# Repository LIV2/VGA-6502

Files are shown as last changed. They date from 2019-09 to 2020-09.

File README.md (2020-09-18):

# VGA-6502
#### 16 colours, 640x480 or 640x400
## Description
A VGA card for my homebrew computer using the Altera EPM7128 CPLD  

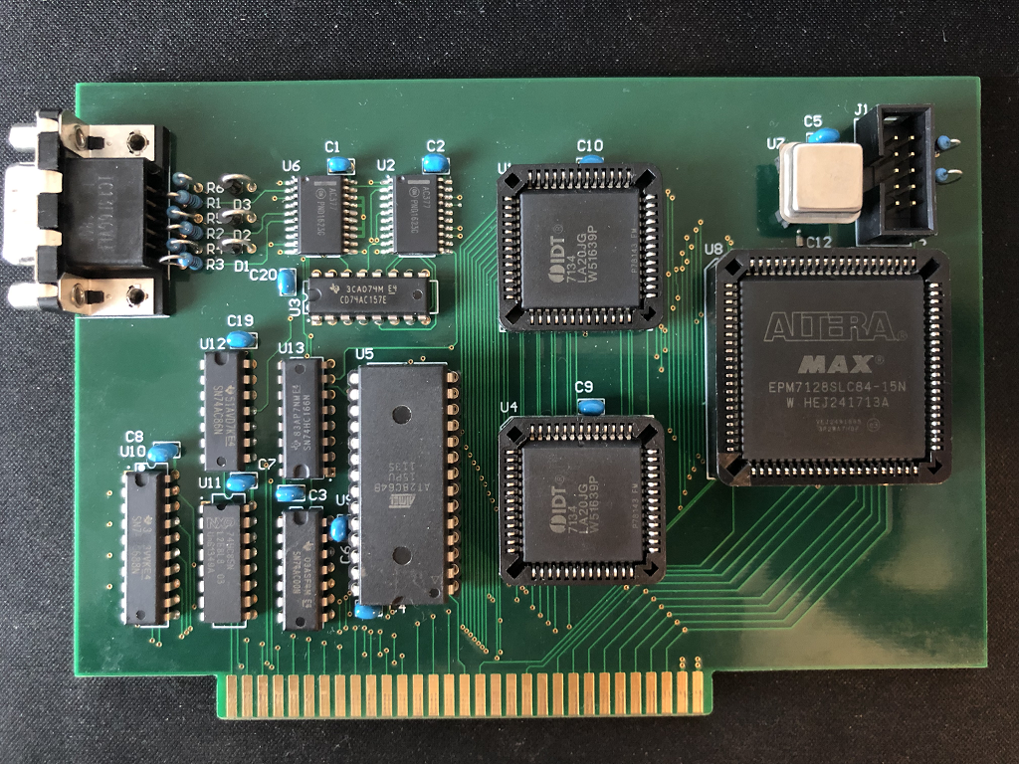
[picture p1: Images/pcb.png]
PCB
  
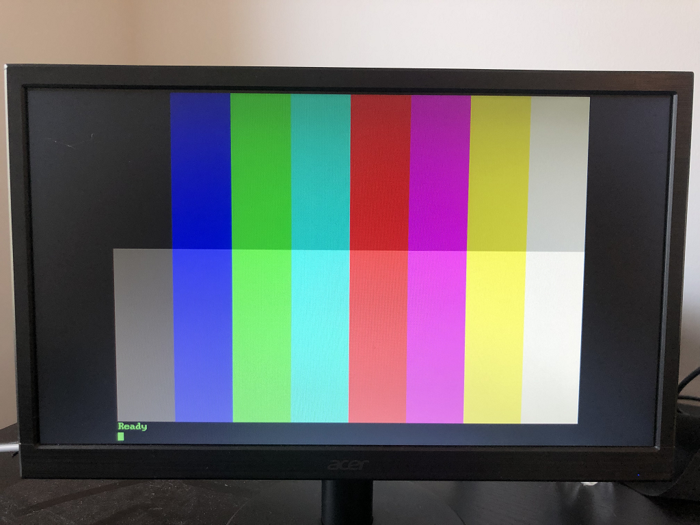
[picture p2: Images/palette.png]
Palette
  
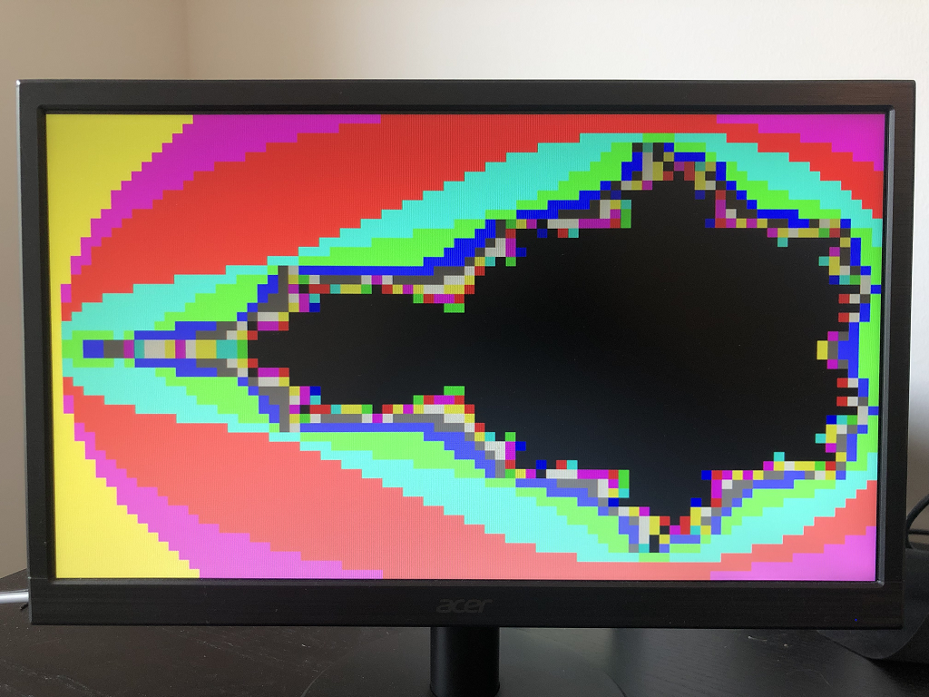
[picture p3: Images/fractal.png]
Fractal
  

Features:
* 16 Colors
* 640x480 and 640x400 modes
* Dual-port RAM
## Palette
|Low intensity|High Intensity|
|---|---|
| 0 - Black| 8 - Dark Gray|
| 1 - Red| 9 - Light Red|
| 2 - Green| 10 - Light Green|
| 3 - Yellow| 11 - Light Yellow|
| 4 - Blue| 12 - Light Blue|
| 5 - Magenta| 13- Light Magenta|
| 6 - Cyan| 14 - Light Cyan|
| 7 - Light Gray| 15 - White|

## Memory layout

### Memory map
GPU: $DF00 (configurable with J5-8)  
RAM: $A000-$BFFF (configurable with J2-4)

### Video RAM
Characters are stored on even addresses, followed by their colour on odd addresses.  
Foreground colour is stored in the lower nibble of the colour byte(s) while background colour is stored in the higher nibble of the colour byte(s)

Example: "Hello world!" with a green foreground and black background would be stored in memory as follows:

|$00|$01|$02|$03|$04|$05|$06|$07|$08|$09|$0A|$0B|$0C|$0D|$0E|$0F|$10|$11|$12|$13|$14|$15|$16|$17|
|---|---|---|---|---|---|---|---|---|---|---|---|---|---|---|---|---|---|---|---|---|---|---|---|
'H'|$0A|'e'|$0A|'l'|$0A|'l'|$0A|'o'|$0A|' '|$0A|'w'|$0A|'o'|$0A|'r'|$0A|'l'|$0A|'d'|$0A|'!'|$0A|

## Registers  
**All registers are currently write-only as I did not have enough space in the CPLD to allow reading from the registers.**  
$DF00: Register Pointer  
$DF01: Register set by Register pointer  

|Register|Description|
|---|---|
|$00|Memory start address(Low byte)|
|$01|Memory start address(High byte)|
|$02|Control register|
|$03|Cursor location (Low byte)|
|$04|Cursor location (High byte)|

### Register pointer (write only)
To access a register you first need to write the register address to the register pointer (default: $DF00), then read/write the register at (default: $DF01)

### Memory Start address (write only)
This register pair forms a 16-bit memory address defining the start of the visual screen, i.e at the start of each frame the VGA controller begins reading characters from here
### Control Register (write only)
The control register configures various settings for the VGA controller 

|Bit(s)|Description|
|---|---|
|7|Character ROM bank select|
|6|Cursor Enable|
|5|Cursor Flash|
|4|Mode|
|3..0|Character Height|

**Bank Select:** Switch font (only valid in Mode 1, 8 Pixel character height)  
**Cursor enable**: Enable the cursor  
**Cursor Flash**: Enable cursor flashing  
**Mode**: Mode 0: 640x480, Mode 1: 640x400  (mode 1 will select the 8x8 fonts from the CGROM)  
**Character Height**: Character height, Default: 0xF (16 pixels)

### Cursor location (write only)
This register pair forms a 16-bit address defining where the cursor should be displayed

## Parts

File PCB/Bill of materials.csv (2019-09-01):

Comment | Description | Designator | Quantity
0.1uF | Multilayer Ceramic Capacitor, Gold Max, C320 Series, 0.1 - F, - 10%, X7R, 50 V, Radial Leaded | C1, C2, C3, C4, C5, C6, C7, C8, C9, C10, C19, C20 | 12
0.1uF | 0603 0.1uF Capacitor | C11, C12, C13, C14, C15, C16, C17, C18 | 8
FCI ICD15S13E6GV00LF | Conn High Density D-Sub SKT 15 POS 2.28mm Solder RA Thru-Hole 15 Terminal 1 Port | CON1 | 1
1N5818 | DO-41 diode vertically mounted | D1, D2, D3 | 3
750 | Generic through-hole resistor vertically mounted | R1, R2, R3 | 3
1k5 | 1k5, Generic through-hole resistor vertically mounted, Generic through-hole resistor vertically mounted | R4, R5, R6 | 3
1k | 1k | R7 | 1
10k | Generic through-hole resistor vertically mounted | R8 | 1
IDT7134LA20JG | 4K x 8 DUAL-PORT STATIC SRAM | U1, U4 | 2
74AC377 | Flip Flop D-Type Bus Interface Pos-Edge 1-Element Automotive 20-Pin SOIC W Tube | U2, U6 | 2
74HC157N | Logic IC - Multiplexer Texas Instruments SN74HC157N Multiplexer Single supply PDIP 16 | U3 | 1
AT28C64B | AT28C64B Series 64 KB (8 K x 8) 5.5 V High-Performance Parallel EEPROM - DIP-28 | U5 | 1
OSC | Oscillator XO 5MHz ??50ppm 50pF (Stability) HCMOS/TTL 55% 5V 4-Pin Metal DIP Thru-Hole Tray | U7 | 1
EPM7128SLC84-15N | CPLD MAX 7000 Family 2.5K Gates 128 Macro Cells 76.9MHz 5V 84-Pin PLCC | U8 | 1
74AC00N | Semiconductors and Actives, Logic Gates, Single, Logic, Standard | U9 | 1
74HC688N | 8-Bit Identity/Magnitude Comparators (P=Q) with Enable 20-PDIP -40 to 85 | U10 | 1
74HC85N | Magnitude Comparator 4-Bit Non-Inverting 16-Pin PDIP Tube | U11 | 1
74AC86E | XOR Gate 4-Element 2-IN CMOS 14-Pin PDIP Tube | U12 | 1
74AC166 | Shift Register Single 8-Bit Serial/Parallel to Serial 16-Pin PDIP Bulk | U13 | 1

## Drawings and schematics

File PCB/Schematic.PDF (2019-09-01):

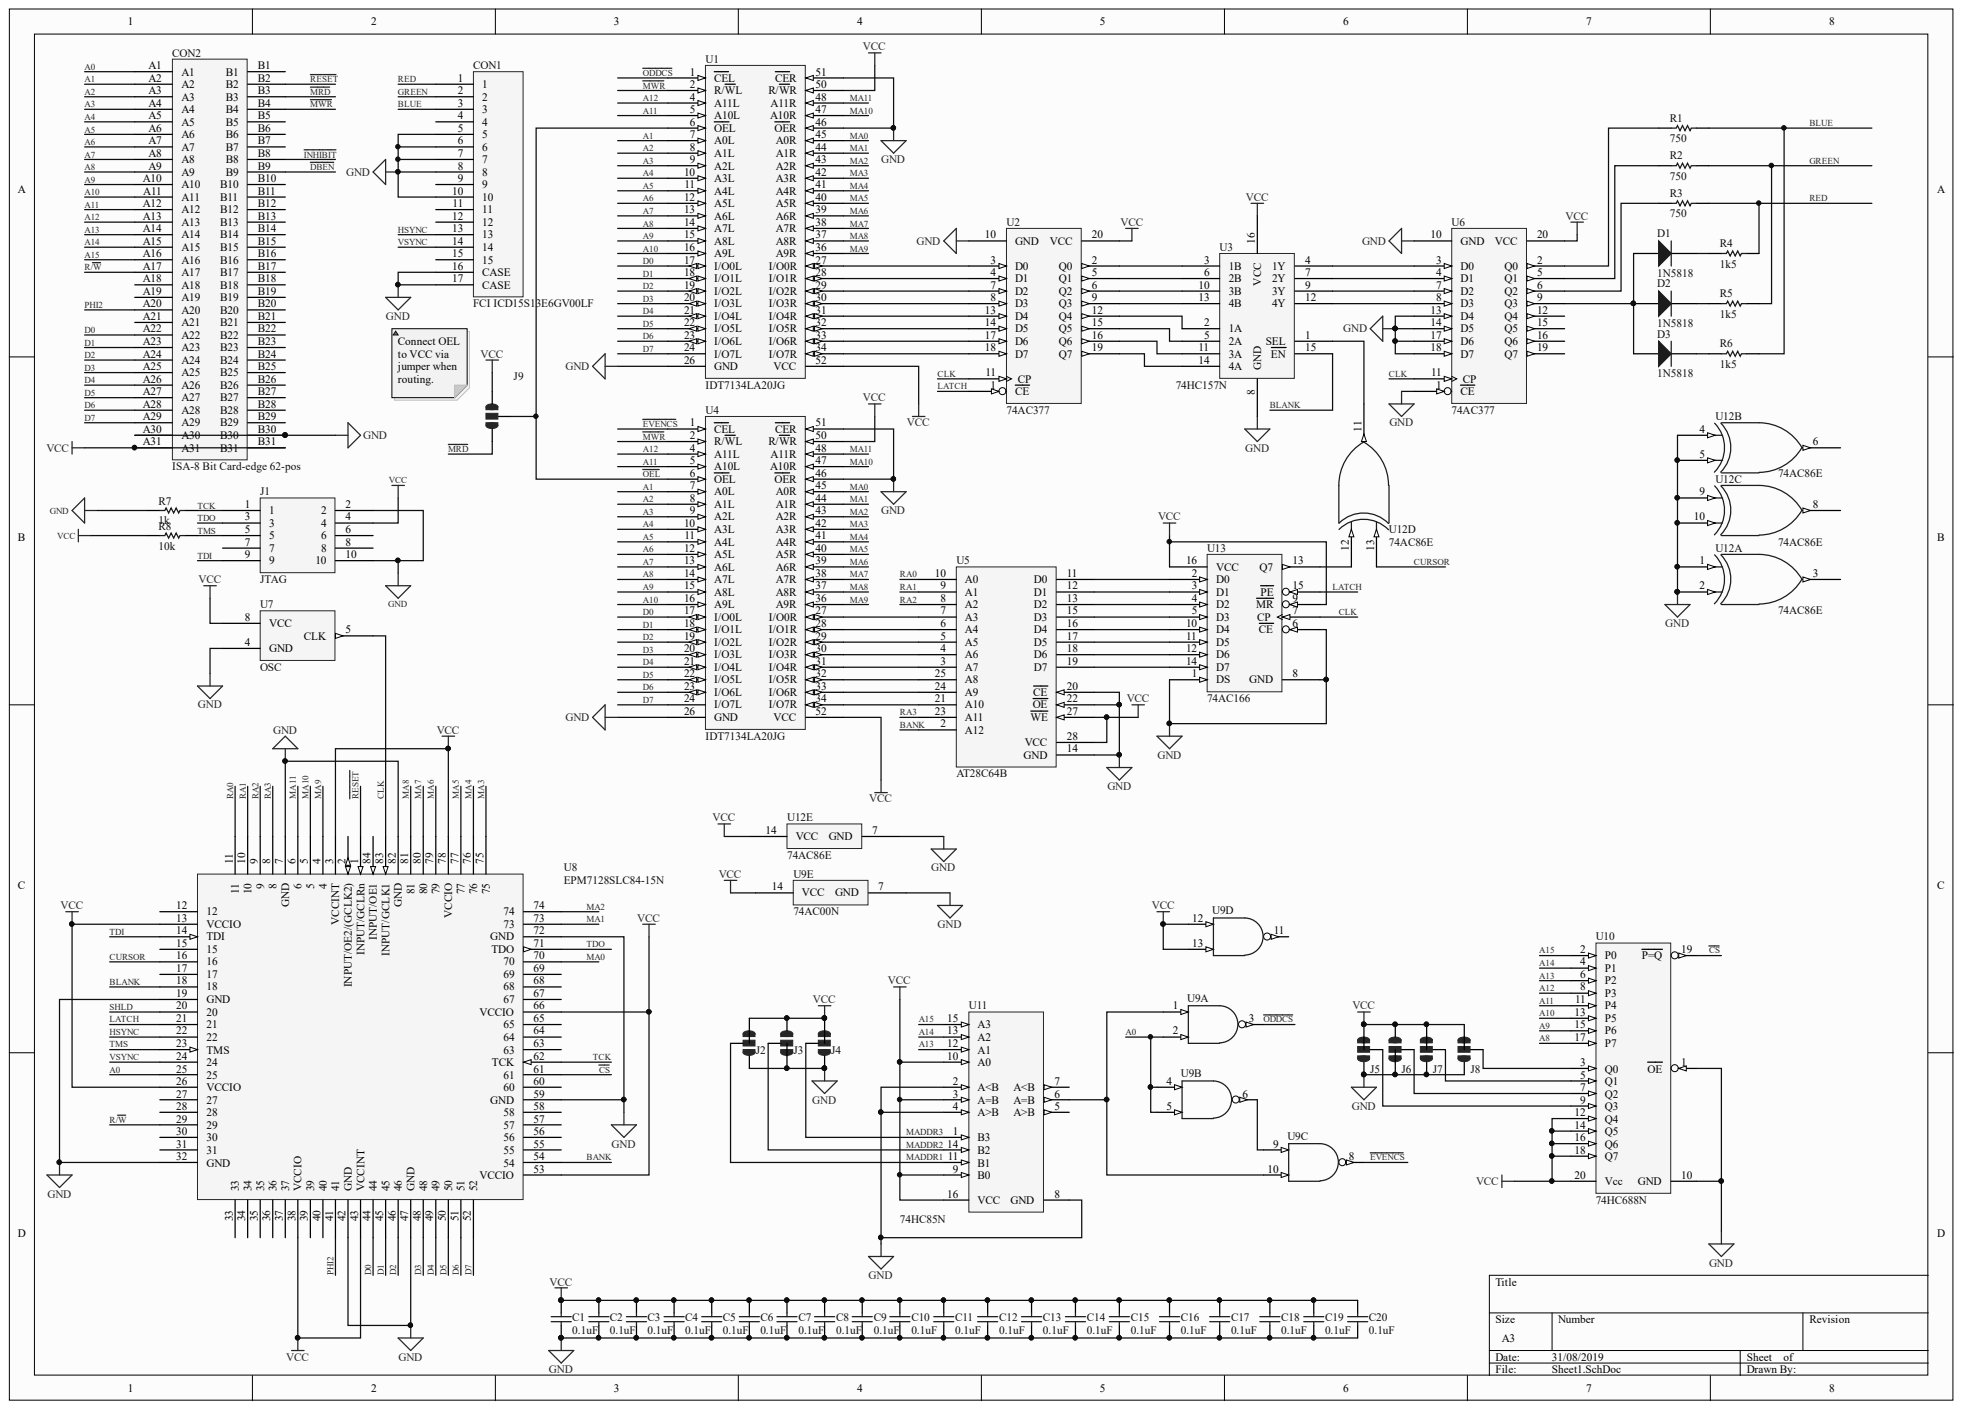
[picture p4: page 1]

ISA-8 Bit Card-edge 62-pos

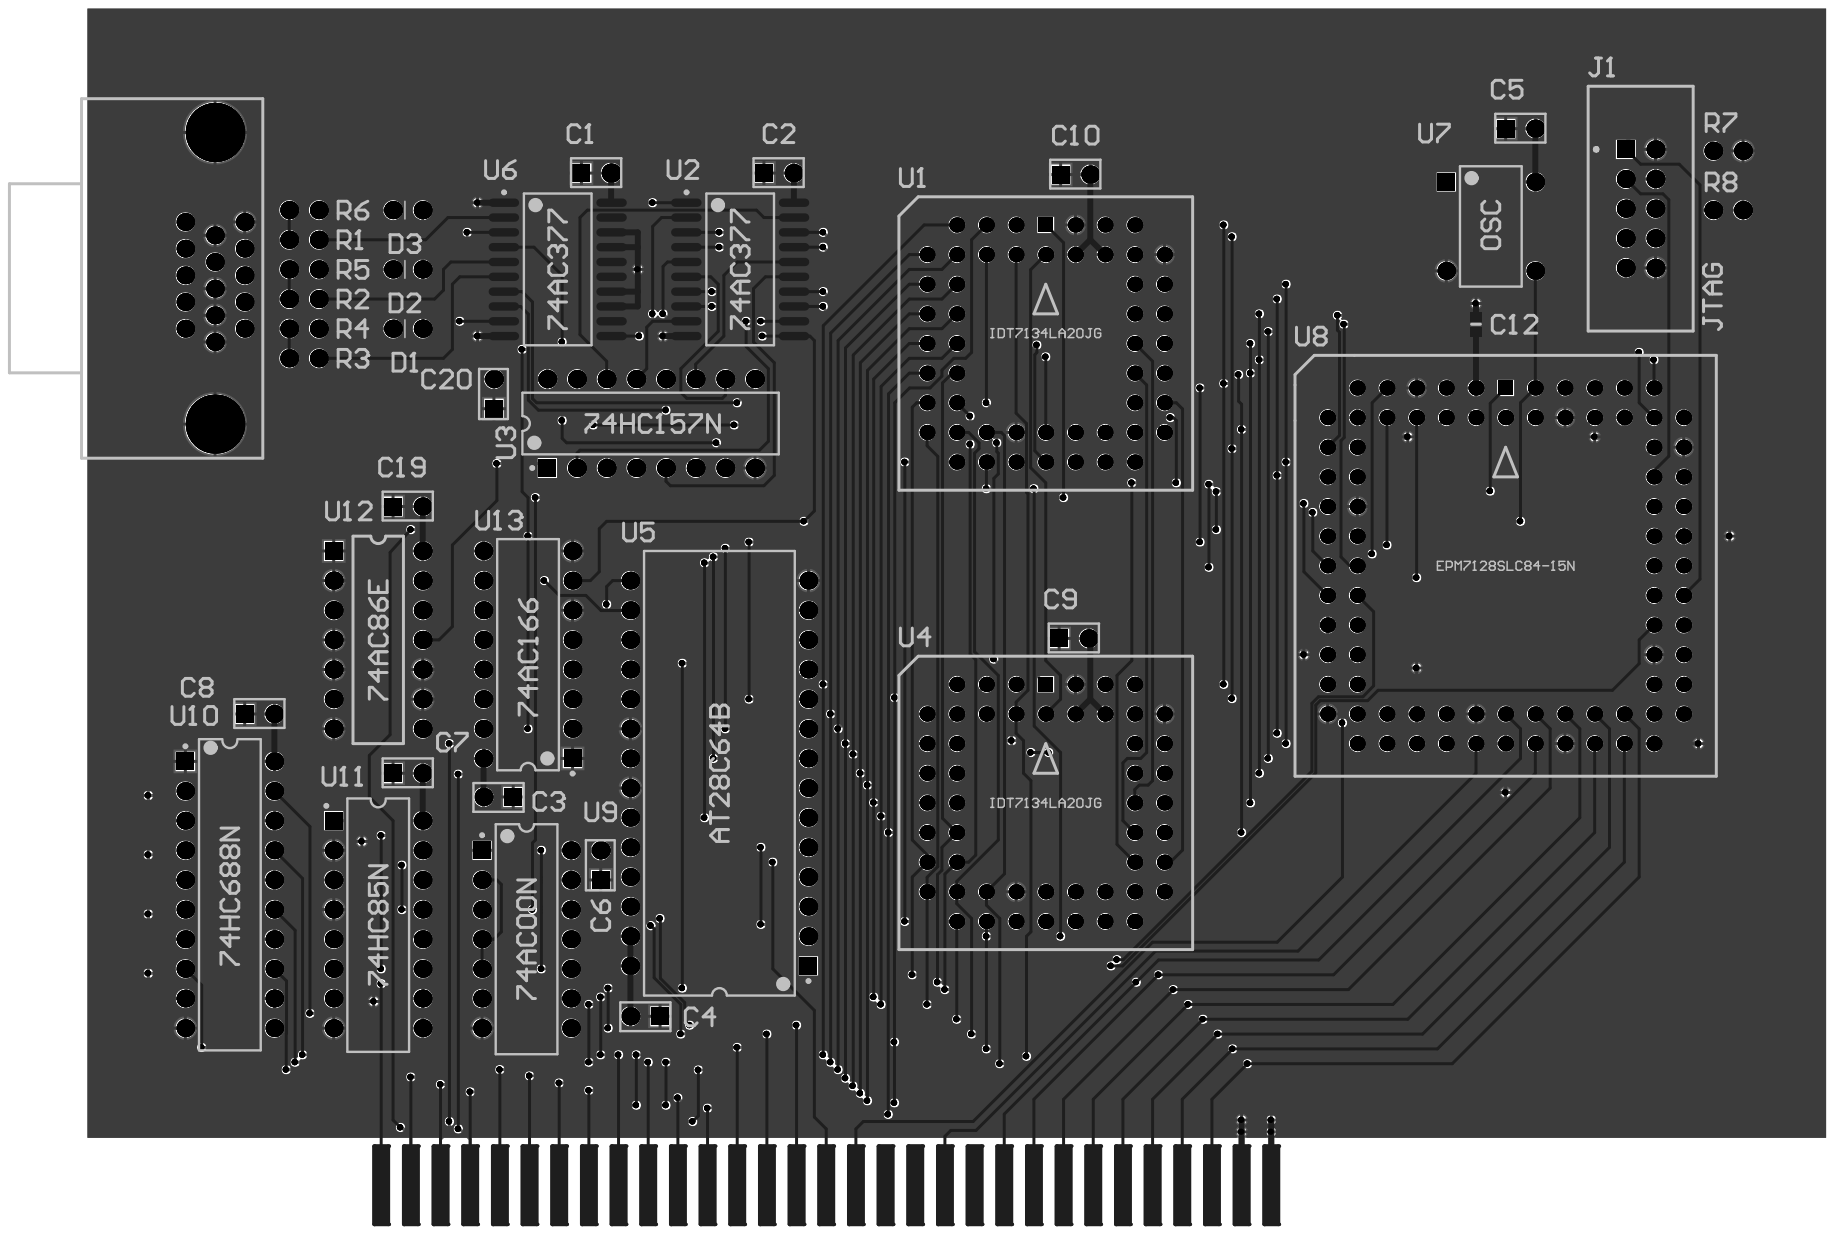
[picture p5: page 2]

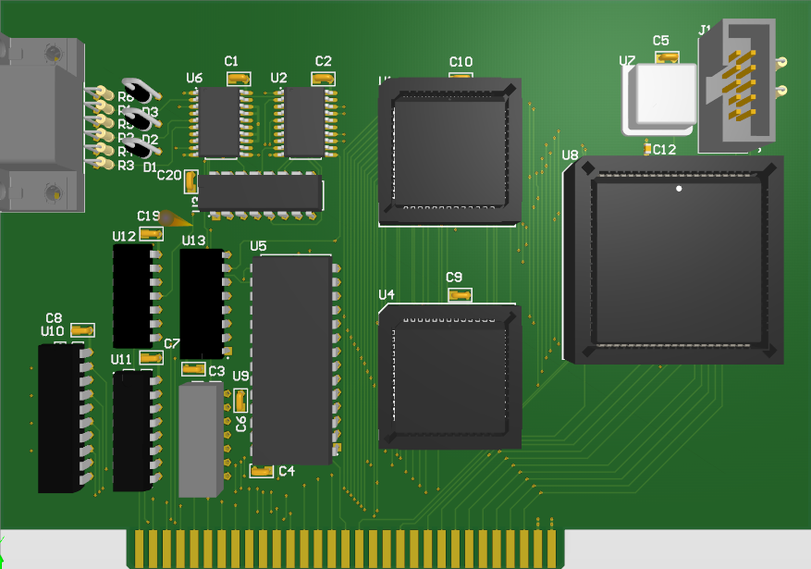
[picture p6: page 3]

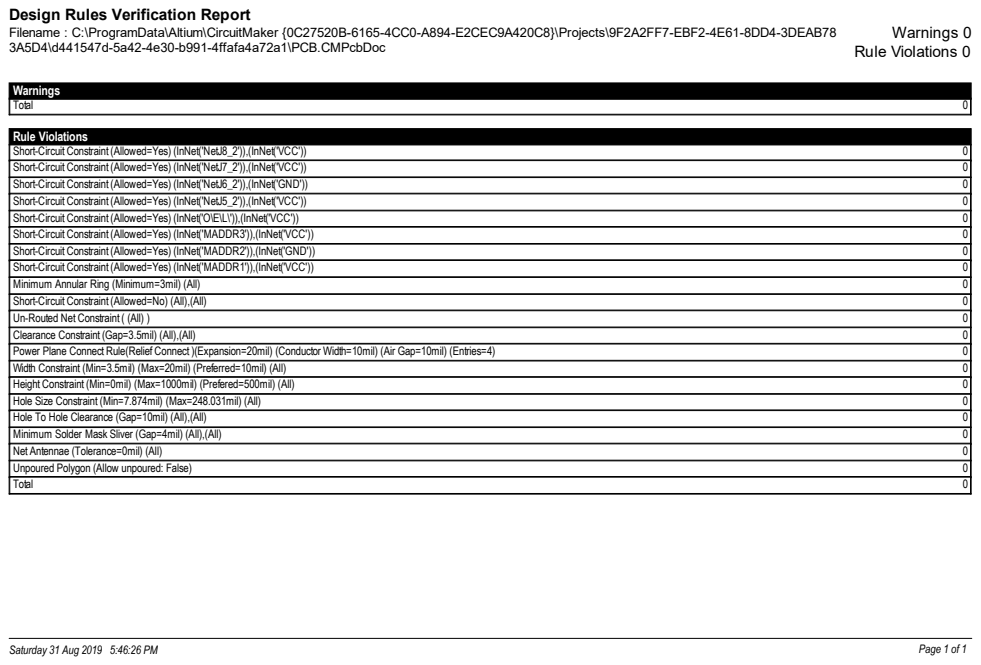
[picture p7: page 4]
Warnings 0 Rule Violations 0; Rule Violations; Short-Circuit Constraint (Allowed=Yes) (InNet('NetJ8_2')),(InNet('VCC')); Short-Circuit Constraint (Allowed=Yes) (InNet('NetJ7_2')),(InNet('VCC')); Short-Circuit Constraint (Allowed=Yes) (InNet('NetJ6_2')),(InNet('GND')); Short-Circuit Constraint (Allowed=Yes) (InNet('NetJ5_2')),(InNet('VCC')); Short-Circuit Constraint (Allowed=Yes) (InNet('O\E\L\')),(InNet('VCC')); Short-Circuit Constraint (Allowed=Yes) (InNet('MADDR3')),(InNet('VCC'))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

Design Rules Verification Report
Filename : C:\ProgramData\Altium\CircuitMaker {0C27520B-6165-4CC0-A894-E2CEC9A420C8}\Projects\9F2A2FF7-EBF2-4E61-8DD4-3DEAB78
3A5D4\d441547d-5a42-4e30-b991-4ffafa4a72a1\PCB.CMPcbDoc

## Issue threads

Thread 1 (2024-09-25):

Programming the Altera EPM7128 CPLD

uesser, 2024-09-25:
Hi,
great work, thank you.
I would like to give it a try for my own 65C02 homebrew computer I‘m about to assemble.

But I‘m a bit lost regarding the EPM7128.
Would you please explain how to program the „Altera EPM7128 CPLD“ chip?
There are 3 files in folder VHDL. I guess thats the firmware!?
But what device to use to get this firmware on the chip? I own a xgeco t48 eeprom programmer but EPM7128 is not on the supported devices list.

Do you have any advice?
Best regards
Udo

LIV2, 2024-09-25:
Hi @uesser

The files in the repo are the source files only, the .jed is not included - but I will build it and add to the repository

Programming the CPLD can only be done via JTAG, the easiest way is to get a cheap Altera Blaster clone on eBay and use Quartus to program the CPLD

The version of Quartus needed is 13.0sp1 which can be found [here](https://www.intel.com/content/www/us/en/software-kit/711791/intel-quartus-ii-web-edition-design-software-version-13-0sp1-for-windows.html) but I don't know if it works on recent windows versions

uesser, 2024-09-25:
Thanks a lot.
I already saw an USB Waveshare blaster on Amazon but was not sure if it is the right tool. It is a JTAG blaster and supports, among others, MAX7000.

Again, thank you very much.
